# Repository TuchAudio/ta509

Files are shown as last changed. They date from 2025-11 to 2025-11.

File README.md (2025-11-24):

# ta509
Improved input selection board

## Purpose
Intended for the **[TuchAudio 309](../../../ta309) _Integrated Amplifier_**, together with:

- [TuchAudio 101b](../../../ta101b) Phono Pre-Amp.
- [TuchAudio 191](../../../ta191) Moving-Coil preamp (optional).
- [TuchAudio 408n](../../../ta408n) simple Volume & Balance Control.
- [TuchAudio 209](../../../ta209) Power Stage (a couple of them for _stereo_).
- [TuchAudio PSU·09](../../../psu09) Power Supply.

## Options
Besides the use of the Moving-Coil pre-amp [191](../../../ta191), which provides a **_switched_ MM/MC Phono input**,
the [408n](../../../ta408n) board might be replaced by the [TuchAudio 409n](../../../ta409n), which adds **Tone controls** (Baxandall-type).

## Inputs
- **Phono with RIAA equalisation:** both DIN and RCA connectors, 3.6 mV/110 kOhm (optional: _Moving Coil_ input via the [191](../../../ta191) board)
- **Line input:** both DIN and RCA connectors, 180 mV/900 kOhm (suitable for _ceramic_ cartridges)
- **Tape Playback:** thru RCA (180 mV/47 k) and DIN (0.48 V/16.5 k) connectors.

## Outputs
- Line out: 180 mV (intended for a suitable poweramp, like [TuchAudio 209](../../../ta209) thru a [408](../../../ta408n)/[409](../../../ta409n) _volume_ board).
- Tape Rec (RCA): 180 mV
- Tape Rec (DIN): 5.3 mV over 10 kohm

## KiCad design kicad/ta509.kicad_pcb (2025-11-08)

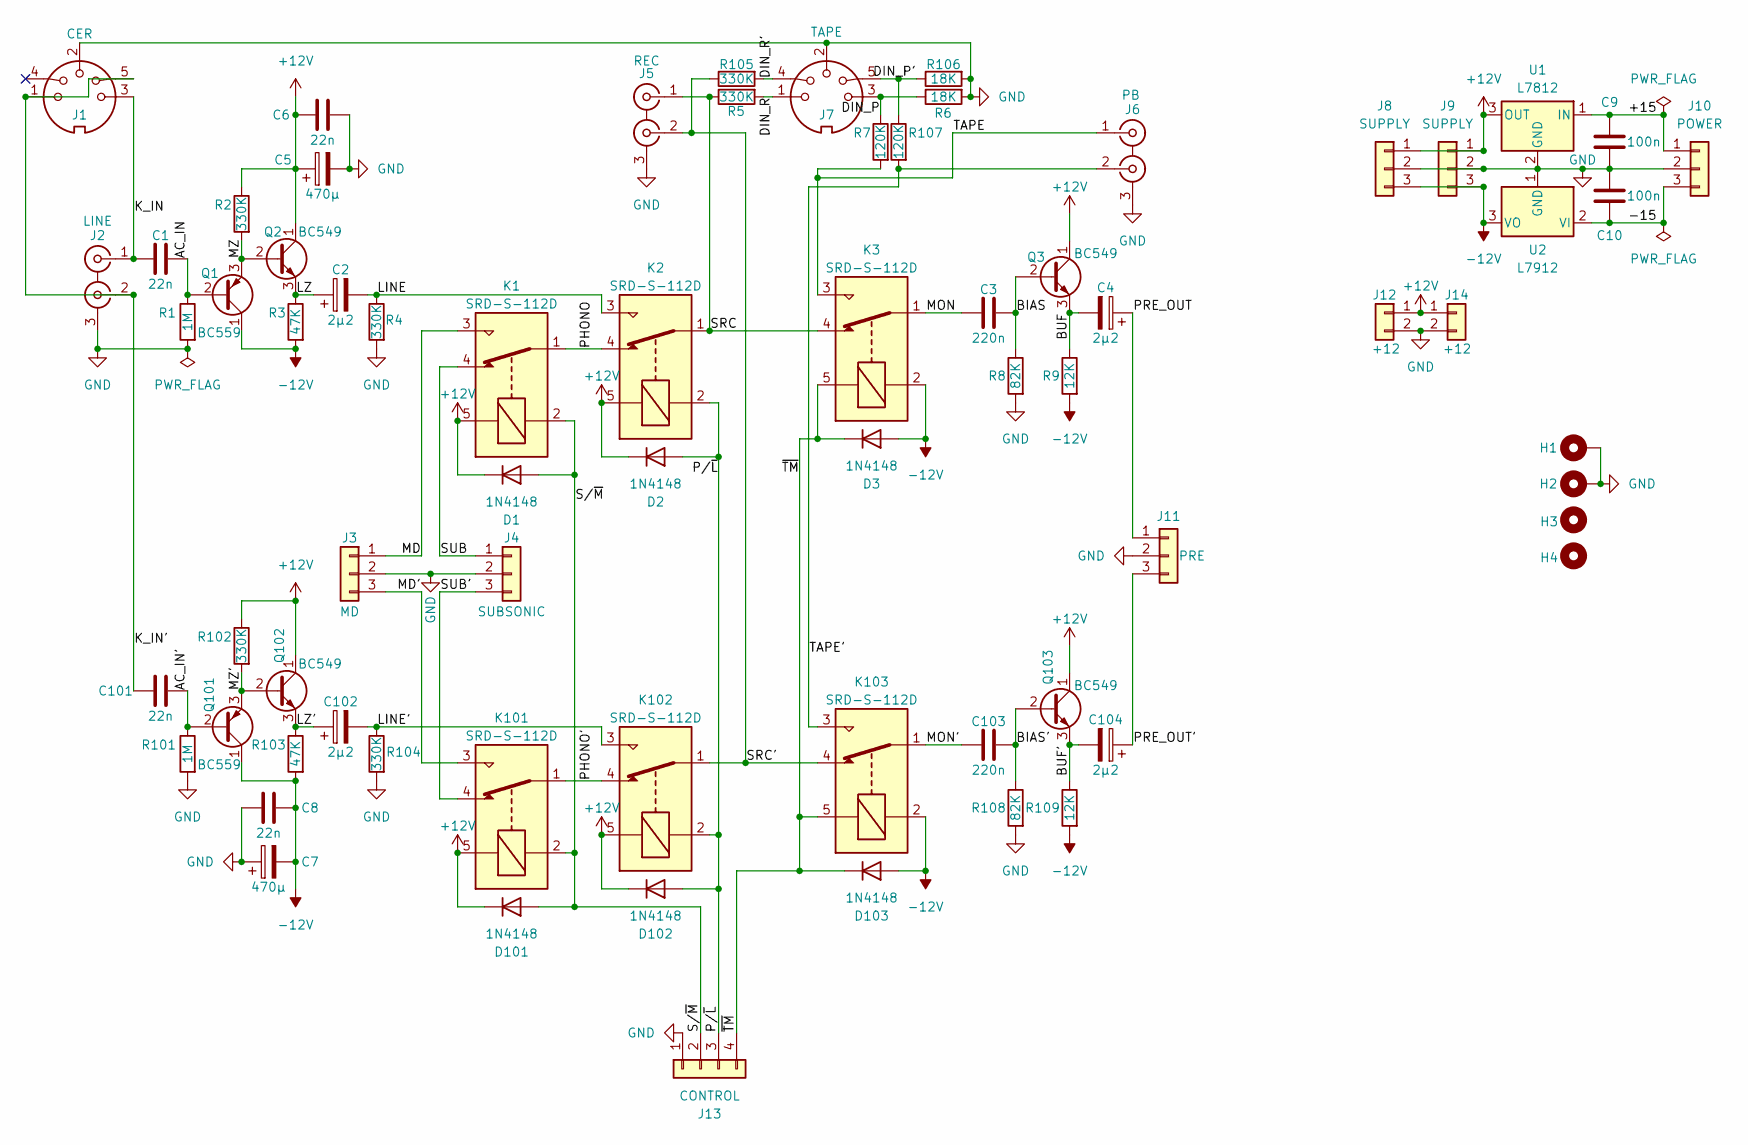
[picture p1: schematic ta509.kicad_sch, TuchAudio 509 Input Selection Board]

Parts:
C1, C101: 22n; C_Rect_L7.2mm_W2.5mm_P5.00mm_FKS2_FKP2_MKS2_MKP2
C2, C4, C102, C104: 2µ2; CP_Radial_D4.0mm_P1.50mm
C3, C103: 220n; C_Rect_L7.2mm_W3.5mm_P5.00mm_FKS2_FKP2_MKS2_MKP2
C5, C7: 470µ; CP_Radial_D10.0mm_P5.00mm
C6, C8: 22n; C_Disc_D6.0mm_W2.5mm_P5.00mm
C9, C10: 100n; C_Rect_L7.2mm_W2.5mm_P5.00mm_FKS2_FKP2_MKS2_MKP2
D1, D2, D3, D101, D102, D103: 1N4148; D_DO-35_SOD27_P7.62mm_Horizontal
H1, H2: MountingHole_Pad; MountingHole_3.2mm_M3_DIN965_Pad
H3, H4: MountingHole; MountingHole_3.2mm_M3_DIN965
J1: CER; DIN 5-180deg
J2: LINE; 2xRCA_vertical
J3: MD; PinHeader_1x03_P2.54mm_Vertical
J4: SUBSONIC; PinHeader_1x03_P2.54mm_Vertical
J5: REC; 2xRCA_vertical
J6: PB; 2xRCA_vertical
J7: TAPE; DIN 5-180deg
J8, J9: SUPPLY; PinHeader_1x03_P2.54mm_Vertical
J10: POWER; PinHeader_1x03_P2.54mm_Vertical
J11: PRE; PinHeader_1x03_P2.54mm_Vertical
J12, J14: +12; PinHeader_1x02_P2.54mm_Vertical
J13: CONTROL; PinHeader_1x04_P2.54mm_Vertical
K1, K2, K3, K101, K102, K103: SRD-S-112D; Relay_SPDT_SANYOU_SRD_Series_Form_C
Q1, Q101: BC559; TO-92_Inline
Q2, Q3, Q102, Q103: BC549; TO-92_Inline
R1, R101: 1M; R_Axial_DIN0207_L6.3mm_D2.5mm_P10.16mm_Horizontal
R2, R4, R5, R102, R104, R105: 330K; R_Axial_DIN0207_L6.3mm_D2.5mm_P10.16mm_Horizontal
R3, R103: 47K; R_Axial_DIN0207_L6.3mm_D2.5mm_P10.16mm_Horizontal
R6, R106: 18K; R_Axial_DIN0207_L6.3mm_D2.5mm_P10.16mm_Horizontal
R7, R107: 120K; R_Axial_DIN0207_L6.3mm_D2.5mm_P10.16mm_Horizontal
R8, R108: 82K; R_Axial_DIN0207_L6.3mm_D2.5mm_P10.16mm_Horizontal
R9, R109: 12K; R_Axial_DIN0207_L6.3mm_D2.5mm_P10.16mm_Horizontal
U1: L7812; TO-220-3_Vertical
U2: L7912; TO-220-3_Vertical

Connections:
+12V: C5.1, C6.1, D1.1 (K), D2.1 (K), D101.1 (K), D102.1 (K), J8.1, J9.1, J12.1, J14.1, K1.5, K2.5, K101.5, K102.5, Q2.1 (C), Q3.1 (C), Q102.1 (C), Q103.1 (C), R2.1, R102.1, U1.3 (OUT)
-12V: C7.2, C8.1, D3.2 (A), D103.2 (A), J8.3, J9.3, K3.2, K103.2, Q1.1 (C), Q101.1 (C), R3.2, R9.2, R103.2, R109.2, U2.3 (VO)
/+15: C9.2, J10.1, U1.1 (IN)
/-15: C10.1, J10.3, U2.2 (VI)
/AC_IN: C1.2, Q1.2 (B), R1.1
/AC_IN': C101.2, Q101.2 (B), R101.1
/BIAS: C3.2, Q3.2 (B), R8.1
/BIAS': C103.2, Q103.2 (B), R108.1
/BUF: C4.2, Q3.3 (E), R9.1
/BUF': C104.2, Q103.3 (E), R109.1
/DIN_P: J7.3, R6.1, R7.1
/DIN_P': J7.5, R106.1, R107.1
/DIN_R: J7.1, R5.2
/DIN_R': J7.4, R105.2
/K_IN: C1.1, J1.3, J2.1 (IN1)
/K_IN': C101.1, J1.1, J1.5, J2.2 (IN2)
/LINE: C2.2, K2.3, R4.1
/LINE': C102.2, K102.3, R104.1
/LZ: C2.1, Q2.3 (E), R3.1
/LZ': C102.1, Q102.3 (E), R103.1
/MD: J3.1, K1.3
/MD': J3.3, K101.3
/MON: C3.1, K3.1
/MON': C103.1, K103.1
/MZ: Q1.3 (E), Q2.2 (B), R2.2
/MZ': Q101.3 (E), Q102.2 (B), R102.2
/PHONO: K1.1, K2.4
/PHONO': K101.1, K102.4
/PRE_OUT: C4.1, J11.1
/PRE_OUT': C104.1, J11.3
/P/~L: D2.2 (A), D102.2 (A), J13.3, K2.2, K102.2
/SRC: J5.1 (IN1), K2.1, K3.4, R5.1
/SRC': J5.2 (IN2), K102.1, K103.4, R105.1
/SUB: J4.1, K1.4
/SUB': J4.3, K101.4
/S/~M: D1.2 (A), D101.2 (A), J13.2, K1.2, K101.2
/TAPE: J6.1 (IN1), K3.3, R7.2
/TAPE': J6.2 (IN2), K103.3, R107.2
/~TM: D3.1 (K), D103.1 (K), J13.4, K3.5, K103.5
GND: C5.2, C6.2, C7.1, C8.2, C9.1, C10.2, H1.1, H2.1, J1.2, J2.3 (EXT), J3.2, J4.2, J5.3 (EXT), J6.3 (EXT), J7.2, J8.2, J9.2, J10.2, J11.2, J12.2, J13.1, J14.2, R1.2, R4.2, R6.2, R8.2, R101.2, R104.2, R106.2, R108.2, U1.2 (GND), U2.1 (GND)

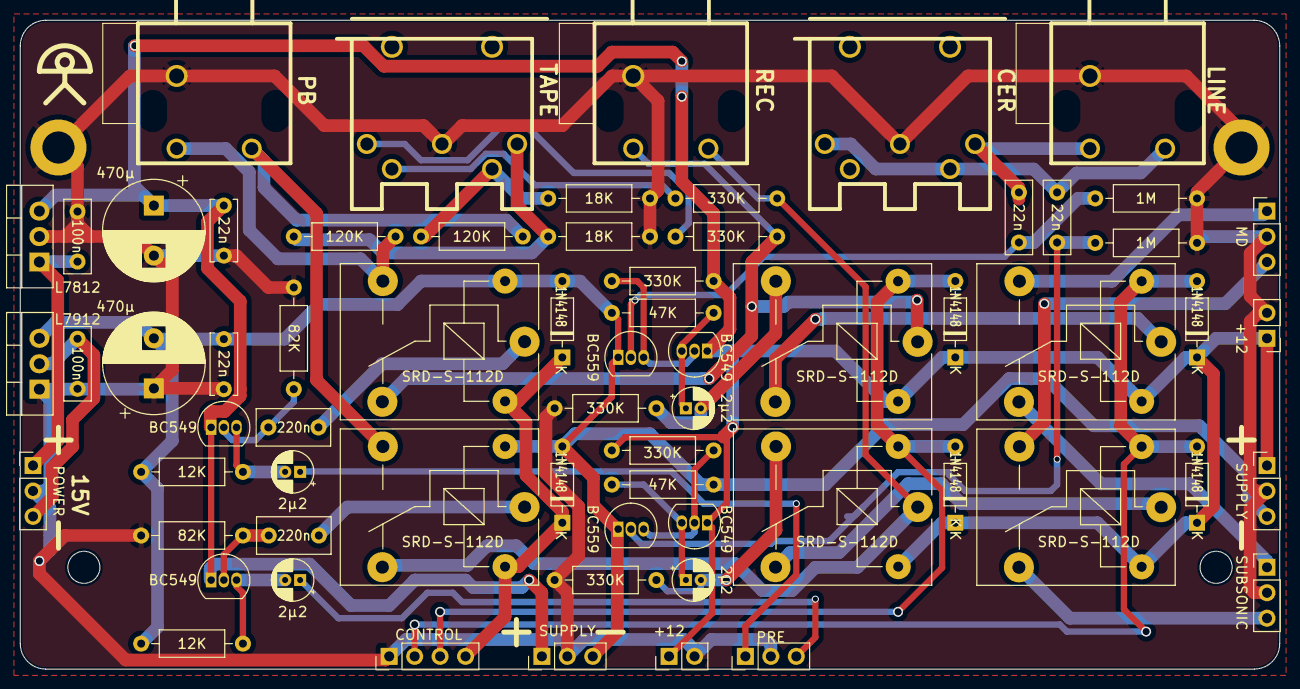
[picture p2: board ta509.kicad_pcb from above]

Board: 2 copper layers, 125.7 x 64.8 mm, 70 parts (0 on the bottom side), 40 nets.

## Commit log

2025-11-08 add KiCAD files
    [ta509.kicad_pcb, ta509.kicad_sch]
2025-11-10 describe suggested boards and inputs
    Added purpose, options, and inputs sections to README.
